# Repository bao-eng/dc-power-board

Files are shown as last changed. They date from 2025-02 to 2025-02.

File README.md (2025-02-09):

# dc-power-board
9-36V DC input 5.1V/5A output board for Raspberry Pi

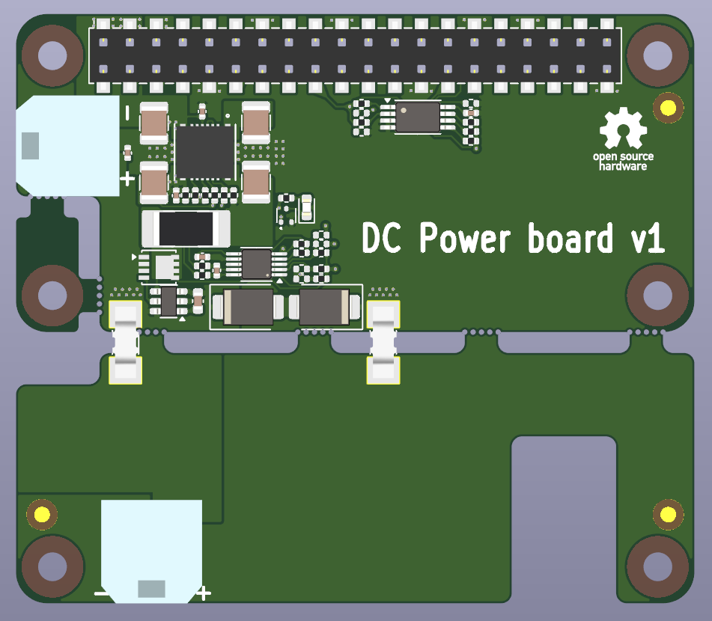
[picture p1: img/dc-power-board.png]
DC Power board


## Features
- 9-36V DC input
- 5.1V/5A output(sufficient to power Raspberry Pi5)
- Reverse polarity protection
- INA226 current, voltage and power monitor
- EEPROM for board identification

## EEPROM
### eep file preparation
```eepmake ./dc_power_board_v1_eeprom.txt dc_power_board_v1.eep```
### EEPROM flashing
Short TP1 and TP2 or short R24 to disable EEPROM write protection. \
Run: ```sudo eepflash.sh -w -f=dc_power_board_v1.eep -t=24c32 -a=53```

## Device tree overlay
### Device tree overlay compilation
```dtc -@ -Hepapr -I dts -O dtb -o dc-power-board-v1.dtbo dc-power-board-v1.dts```

### dtbo installation
Copy ```dc-power-board-v1.dtbo``` to the ```/boot/overlays/``` directory.

## Power monitor usage
### Get current in mA
```cat /sys/devices/platform/soc/fe804000.i2c/i2c-1/1-0045/hwmon/hwmon2/curr1_input```

### Get voltage in mV
```cat /sys/devices/platform/soc/fe804000.i2c/i2c-1/1-0045/hwmon/hwmon2/in1_input```

### Get power in mW
```cat /sys/devices/platform/soc/fe804000.i2c/i2c-1/1-0045/hwmon/hwmon2/power1_input```

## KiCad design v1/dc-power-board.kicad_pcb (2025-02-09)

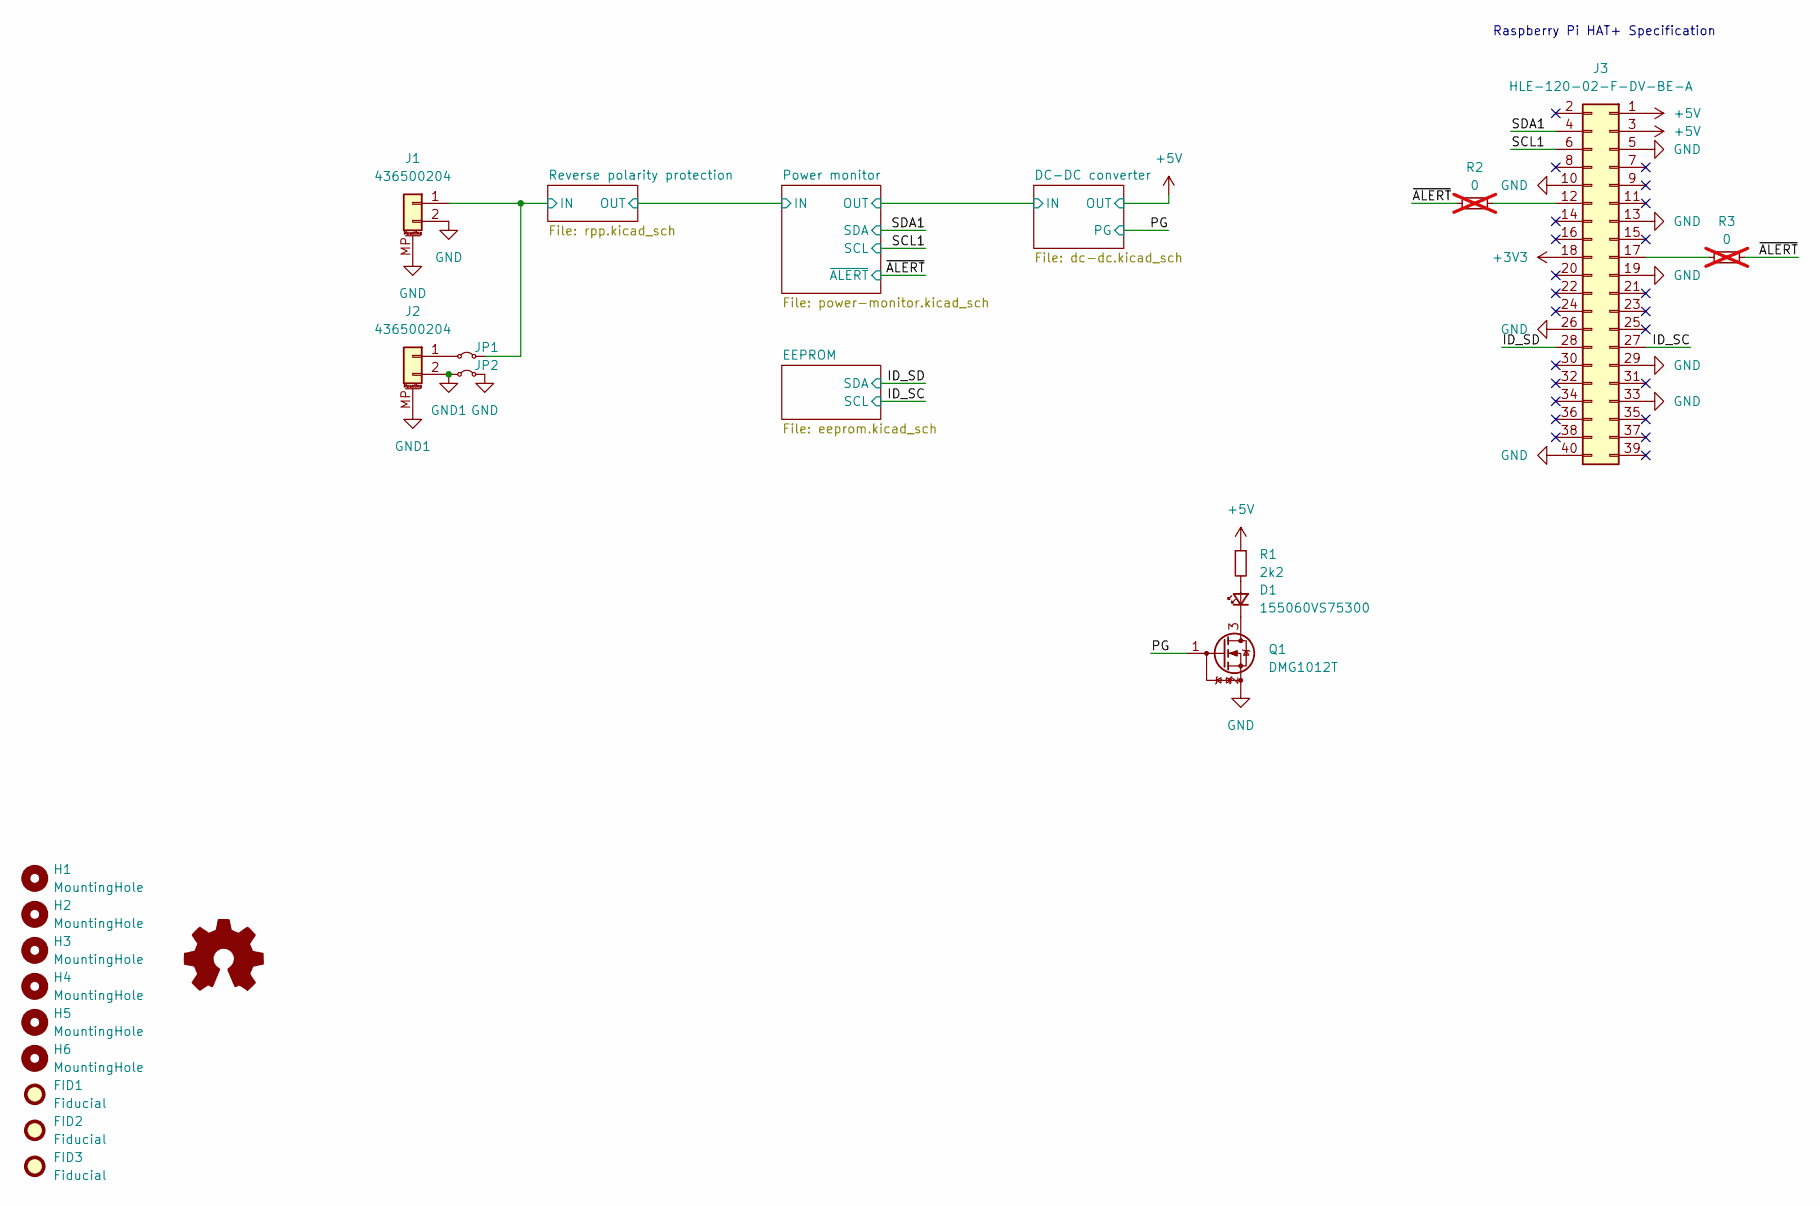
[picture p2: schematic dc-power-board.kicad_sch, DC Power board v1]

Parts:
D1: 155060VS75300; LED_0603_1608Metric
FID1, FID2, FID3: Fiducial; Fiducial_1.5mm_Mask3mm
H1, H2, H3, H4, H5, H6: MountingHole; MountingHole_2.75mm_M2.5
J1, J2: 436500204
J3: HLE-120-02-F-DV-BE-A; Samtec_HLE-120-02-xxx-DV-BE-A_2x20_P2.54mm_Horizontal
JP1, JP2: 0; HARWIN_S1911-46R; MPN S1911-46R
Q1: DMG1012T; SOT-523
R1: 2k2; R_0402_1005Metric; MPN RC0402FR-072K2L
R2, R3: 0; R_0402_1005Metric; MPN RC0402JR-070RL; not fitted
SYM1: Logo_Open_Hardware_Small; OSHW-Logo_5.7x6mm_SilkScreen

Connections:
+3V3: J3.18; also elsewhere on the board
+5V: J3.1, J3.3, R1.1; also elsewhere on the board
/ID_SC: J3.27; also elsewhere on the board
/ID_SD: J3.28; also elsewhere on the board
/PG: Q1.1 (G); also elsewhere on the board
/Reverse polarity protection/IN: J1.1, JP1.2 (B); also elsewhere on the board
/SCL1: J3.6; also elsewhere on the board
/SDA1: J3.4; also elsewhere on the board
/~ALERT: R2.1, R3.2; also elsewhere on the board
GND: J1.2, J1.MP (MountPin), J3.5, J3.10, J3.13, J3.19, J3.26, J3.29, J3.33, J3.40, JP2.2 (B), Q1.2 (S); also elsewhere on the board
GND1: J2.2, J2.MP (MountPin), JP2.1 (A)
unnamed: D1.2 (A), R1.2
unnamed: D1.1 (K), Q1.3 (D)
unnamed: J2.1, JP1.1 (A)
unnamed: J3.12, R2.2
unnamed: J3.17, R3.1

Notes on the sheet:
Raspberry Pi HAT+ Specification

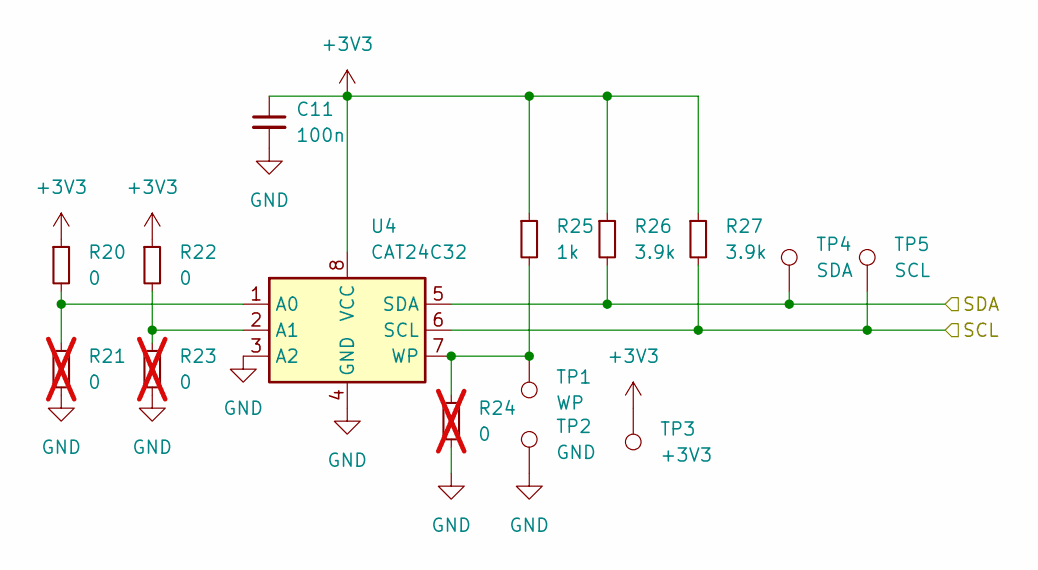
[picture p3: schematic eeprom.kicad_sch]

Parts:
C11: 100n; C_0402_1005Metric; MPN 885012105001
R20, R22: 0; R_0402_1005Metric; MPN RC0402FR-071KL
R21, R23, R24: 0; R_0402_1005Metric; MPN RC0402FR-071KL; not fitted
R25: 1k; R_0402_1005Metric; MPN RC0402FR-071KL
R26, R27: 3.9k; R_0402_1005Metric; MPN RC0402FR-073K9L
TP1: WP; TestPoint_Pad_D2.0mm
TP2: GND; TestPoint_Pad_D2.0mm
TP3: +3V3; TestPoint_Pad_D2.0mm
TP4: SDA; TestPoint_Pad_D2.0mm
TP5: SCL; TestPoint_Pad_D2.0mm
U4: CAT24C32; TSSOP-8_4.4x3mm_P0.65mm; MPN CAT24C32YI-GT3

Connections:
+3V3: C11.1, R20.1, R22.1, R25.1, R26.1, R27.1, TP3.1, U4.8 (VCC); also elsewhere on the board
/ID_SC: R27.2, TP5.1, U4.6 (SCL); also elsewhere on the board
/ID_SD: R26.2, TP4.1, U4.5 (SDA); also elsewhere on the board
GND: C11.2, R21.2, R23.2, R24.2, TP2.1, U4.3 (A2), U4.4 (GND); also elsewhere on the board
unnamed: R20.2, R21.1, U4.1 (A0)
unnamed: R22.2, R23.1, U4.2 (A1)
unnamed: R24.1, R25.2, TP1.1, U4.7 (WP)

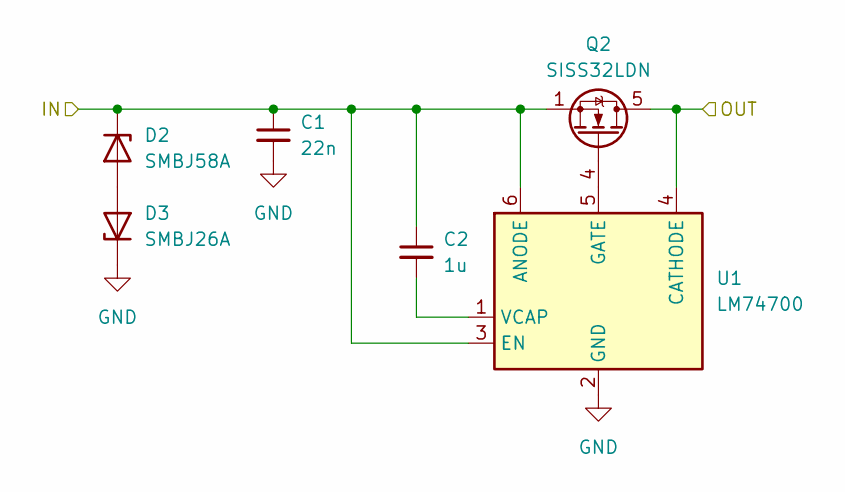
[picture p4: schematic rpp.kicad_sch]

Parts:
C1: 22n; C_0402_1005Metric; MPN GRM155R71H223KA12D
C2: 1u; C_0603_1608Metric; MPN CGA3E1X7R1E105K080AD
D2: SMBJ58A; D_SMB
D3: SMBJ26A; D_SMB
Q2: SISS32LDN; Vishay_PowerPAK_1212-8_Single
U1: LM74700; SOT-23-6; MPN LM74700QDBVRQ1

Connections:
/Power monitor/IN: Q2.5 (D), U1.4 (CATHODE); also elsewhere on the board
/Reverse polarity protection/IN: C1.1, C2.1, D2.1 (K), Q2.1 (S), Q2.2 (S), Q2.3 (S), U1.3 (EN), U1.6 (ANODE); also elsewhere on the board
GND: C1.2, D3.1 (K), U1.2 (GND); also elsewhere on the board
unnamed: D2.2 (A), D3.2 (A)
unnamed: Q2.4 (G), U1.5 (GATE)
unnamed: C2.2, U1.1 (VCAP)

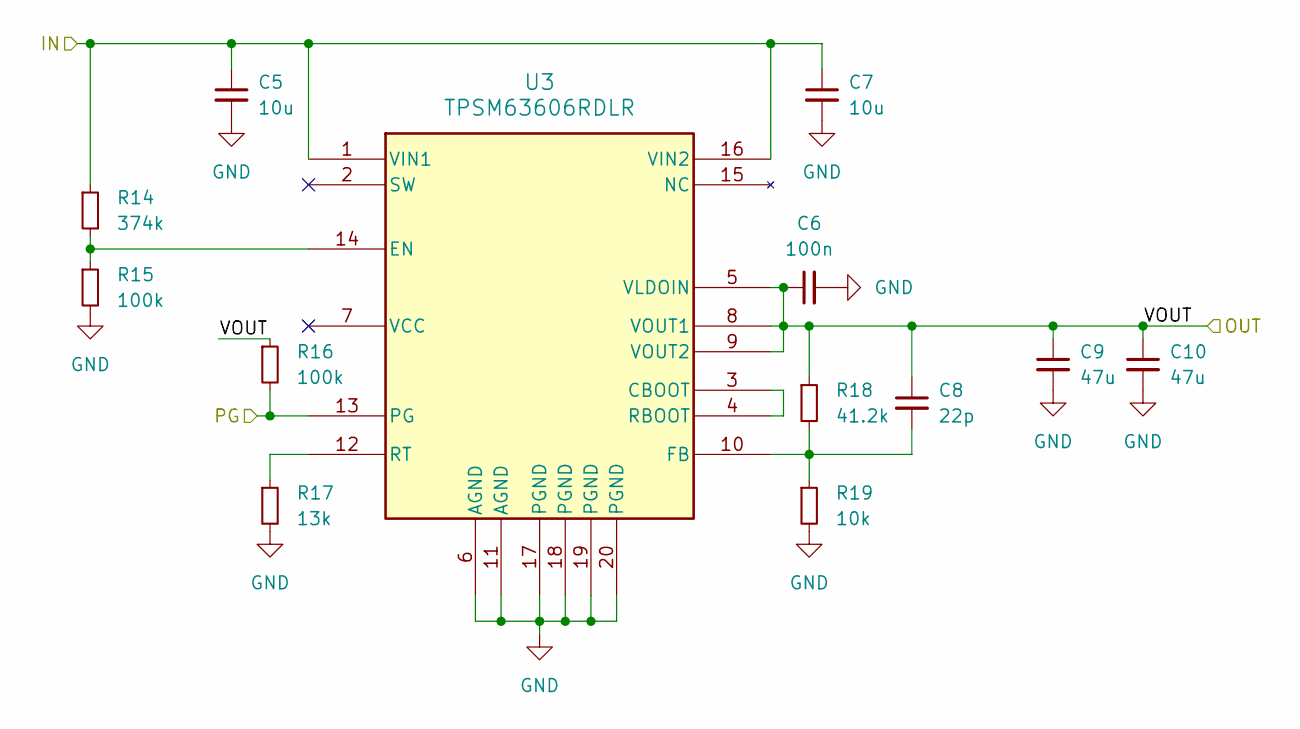
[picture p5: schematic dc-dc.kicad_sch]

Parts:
C5, C7: 10u; C_1210_3225Metric; MPN CNA6P1X7R1H106K
C6: 100n; C_0402_1005Metric; MPN 885012105001
C8: 22p; C_0402_1005Metric; MPN GRM1555C1H220JA01D
C9, C10: 47u; C_1210_3225Metric; MPN GRM32ER71A476ME15L
R14: 374k; R_0402_1005Metric; MPN RC0402FR-07374KL
R15, R16: 100k; R_0402_1005Metric; MPN RC0402FR-07100KL
R17: 13k; R_0402_1005Metric; MPN RC0402FR-0713KL
R18: 41.2k; R_0402_1005Metric; MPN RC0402FR-1341K2L
R19: 10k; R_0402_1005Metric; MPN RC0402JR-0710KL
U3: TPSM63606RDLR; B3QFN20_RDL_TEX

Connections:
+5V: C6.1, C8.1, C9.1, C10.1, R16.1, R18.1, U3.5 (VLDOIN), U3.8 (VOUT1), U3.9 (VOUT2); also elsewhere on the board
/DC-DC converter/IN: C5.1, C7.1, R14.1, U3.1 (VIN1), U3.16 (VIN2); also elsewhere on the board
/PG: R16.2, U3.13 (PG); also elsewhere on the board
GND: C5.2, C6.2, C7.2, C9.2, C10.2, R15.2, R17.2, R19.2, U3.6 (AGND), U3.11 (AGND), U3.17 (PGND), U3.18 (PGND), U3.19 (PGND), U3.20 (PGND); also elsewhere on the board
unnamed: U3.3 (CBOOT), U3.4 (RBOOT)
unnamed: R14.2, R15.1, U3.14 (EN)
unnamed: C8.2, R18.2, R19.1, U3.10 (FB)
unnamed: R17.1, U3.12 (RT)

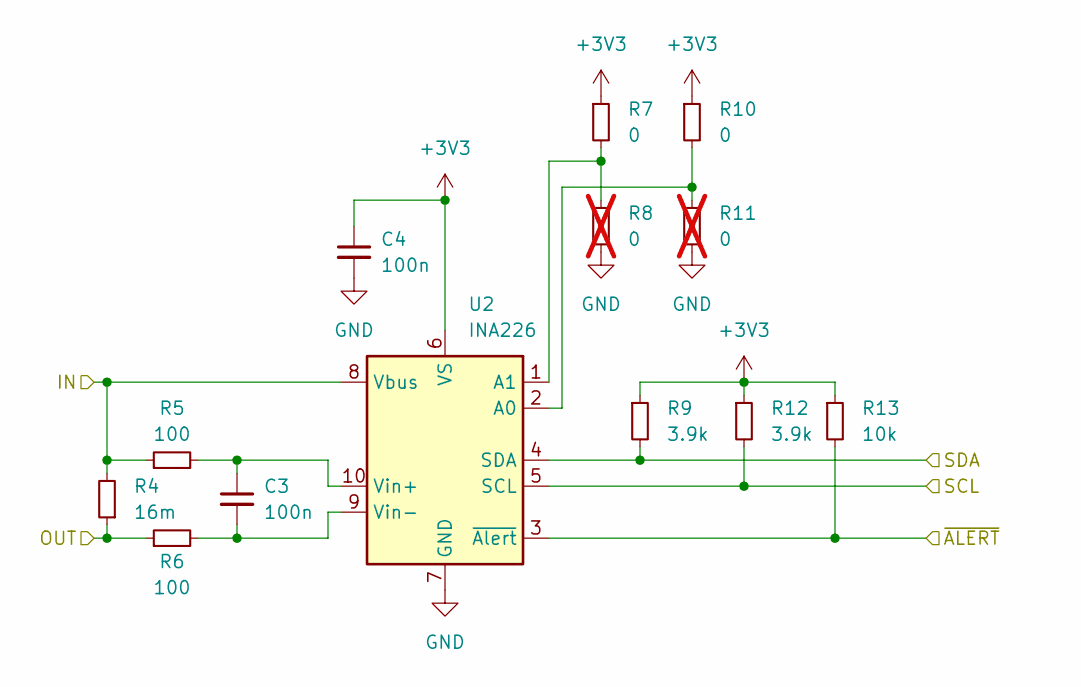
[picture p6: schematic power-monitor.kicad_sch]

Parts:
C3, C4: 100n; C_0402_1005Metric; MPN 885012105001
R4: 16m; R_Shunt_Vishay_WPC2512_6332Metric_R001~R056; MPN WPC2512QLR016FYR
R5, R6: 100; R_0402_1005Metric; MPN RT0402BRD07100RL
R7, R10: 0; R_0402_1005Metric; MPN RC0402JR-070RL
R8, R11: 0; R_0402_1005Metric; MPN RC0402JR-070RL; not fitted
R9, R12: 3.9k; R_0402_1005Metric; MPN RC0402FR-073K9L
R13: 10k; R_0402_1005Metric; MPN RC0402JR-0710KL
U2: INA226; VSSOP-10_3x3mm_P0.5mm

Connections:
+3V3: C4.1, R7.1, R9.1, R10.1, R12.1, R13.1, U2.6 (VS); also elsewhere on the board
/DC-DC converter/IN: R4.1, R6.1; also elsewhere on the board
/Power monitor/IN: R4.2, R5.1, U2.8 (Vbus); also elsewhere on the board
/SCL1: R12.2, U2.5 (SCL); also elsewhere on the board
/SDA1: R9.2, U2.4 (SDA); also elsewhere on the board
/~ALERT: R13.2, U2.3 (~Alert); also elsewhere on the board
GND: C4.2, R8.2, R11.2, U2.7 (GND); also elsewhere on the board
unnamed: R10.2, R11.1, U2.2 (A0)
unnamed: R7.2, R8.1, U2.1 (A1)
unnamed: C3.1, R5.2, U2.10 (Vin+)
unnamed: C3.2, R6.2, U2.9 (Vin-)

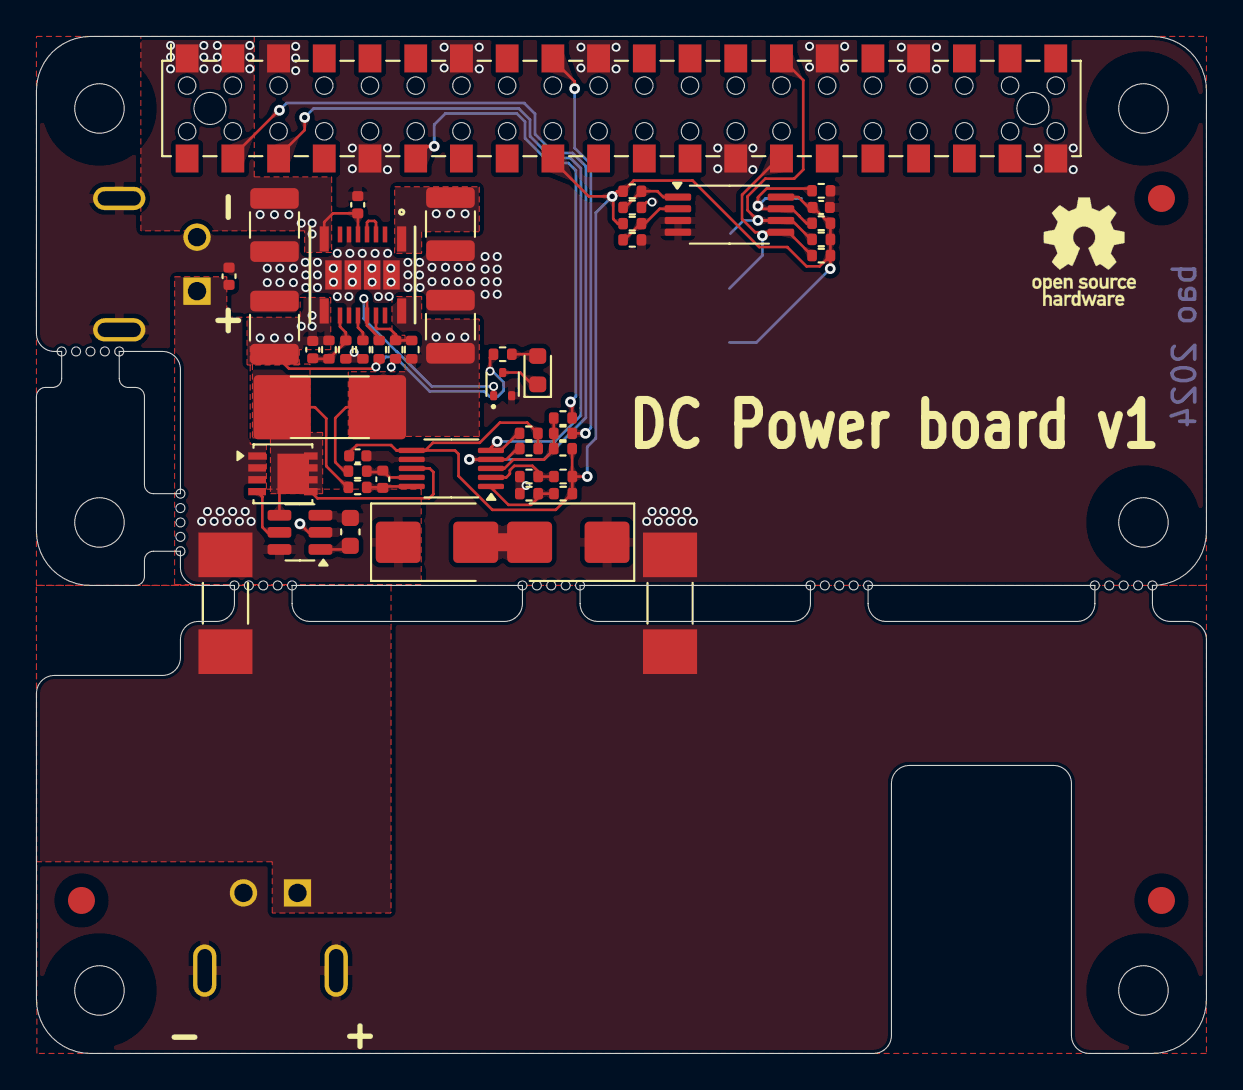
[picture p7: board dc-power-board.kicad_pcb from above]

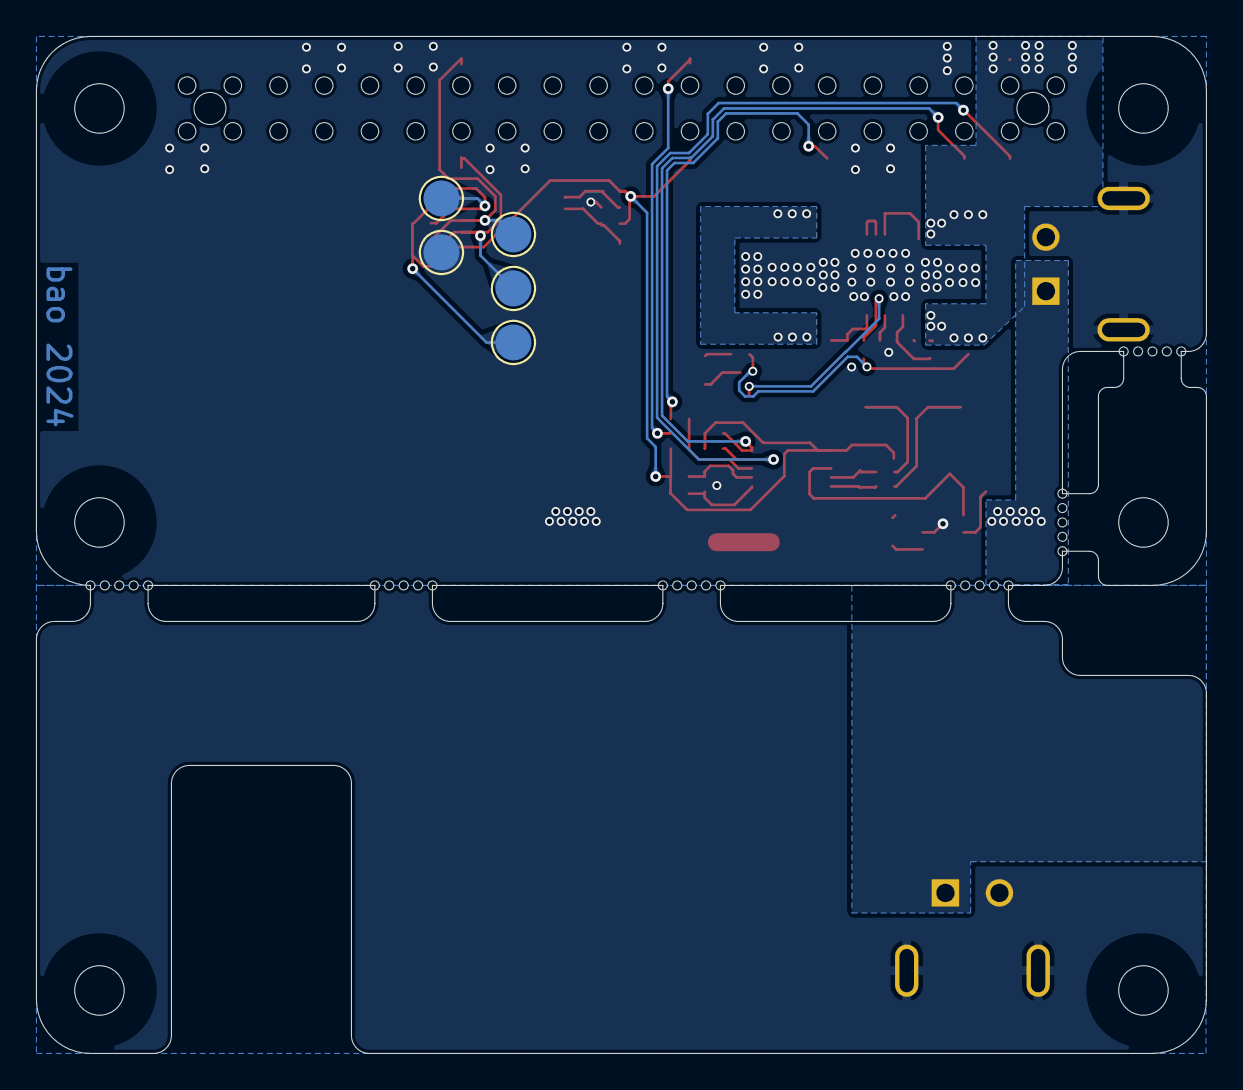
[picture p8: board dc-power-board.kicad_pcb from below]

Board: 2 copper layers, 65.0 x 56.5 mm, 67 parts (5 on the bottom side), 32 nets.
